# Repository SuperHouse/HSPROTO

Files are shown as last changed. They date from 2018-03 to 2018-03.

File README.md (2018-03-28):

HomeSense Proto
===============
Copyright 2018 SuperHouse Pty Ltd  www.superhouse.tv  
Designed by Jonathan Oxer

Prototyping module for ESP8266 projects in a small case suitable
for use in a home automation system. Includes:

 - ESP8266 processor with WiFi
 - Switchmode voltage regulator for wide input voltage range
 - Prototyping area with I/O breakout to add your own parts

More information at

  http://www.superhouse.tv/hsproto

INSTALLATION
------------
The design is saved as an EAGLE project. EAGLE PCB design software is
available from www.cadsoftusa.com free for non-commercial use. To use
this project download it and place the directory containing these files
into the "eagle" directory on your computer. Then open EAGLE and
navigate to the project.

DISTRIBUTION
------------
The specific terms of distribution of this project are governed by the
license referenced below.

LICENSE
-------
Licensed under the TAPR Open Hardware License (www.tapr.org/OHL).
The "license" folder within this repository also contains a copy of
this license in plain text format.

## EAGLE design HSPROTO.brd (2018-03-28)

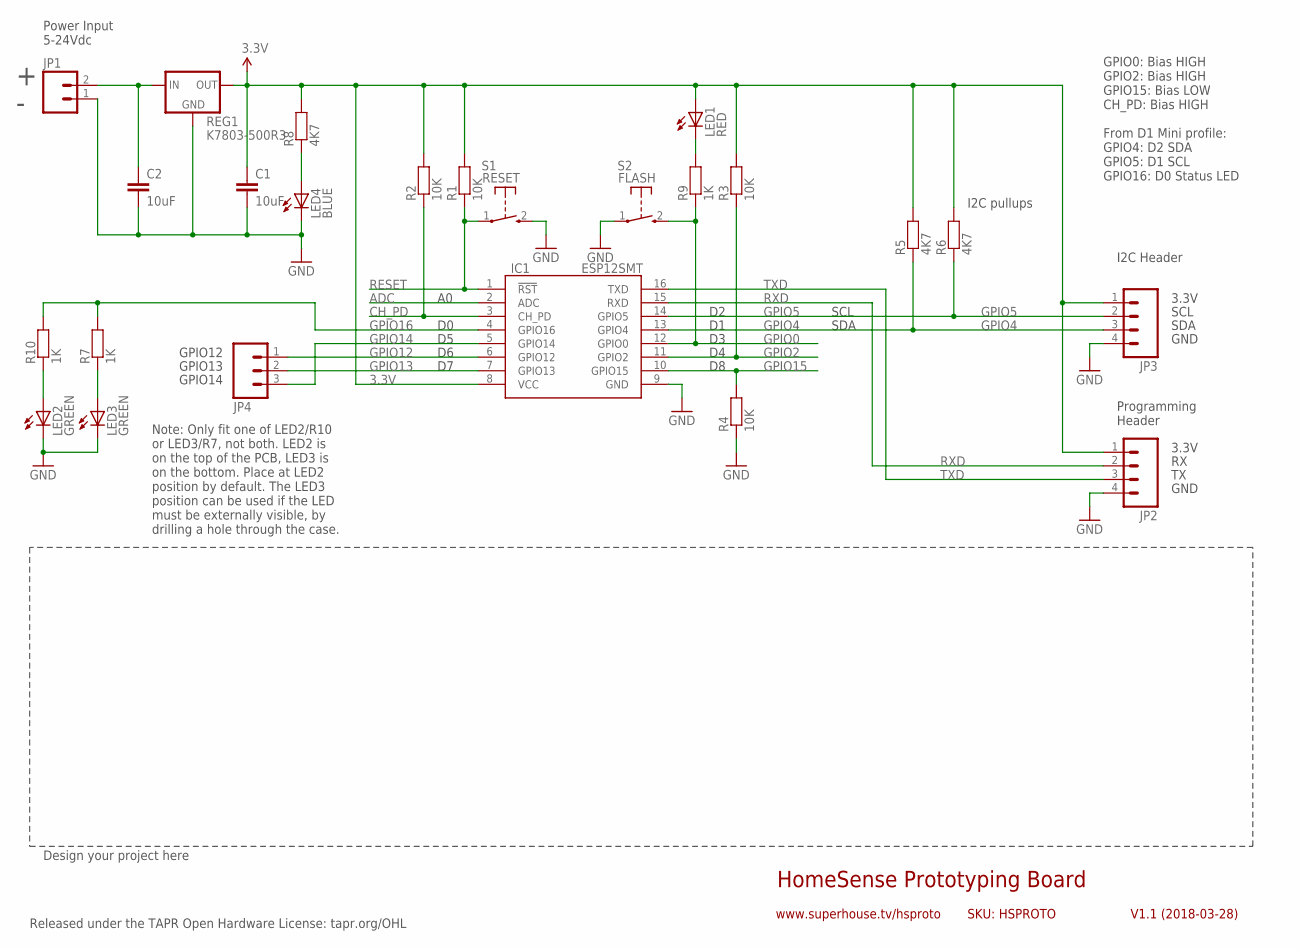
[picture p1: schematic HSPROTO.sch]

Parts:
C1, C2: 10uF; 0805
IC1: ESP12SMT; ESP12
JP1: M02PTH; 1X02
JP2, JP3: M04PTH; 1X04
JP4: M03PTH; 1X03
LED1: RED; LED-0603
LED2, LED3: GREEN; LED-0603
LED4: BLUE; LED-0603
R1, R2, R3, R4: 10K; 0603
R5, R6, R8: 4K7; 0603
R7, R9, R10: 1K; 0603
REG1: K7803-500R3; K78XX-500R3
S1: RESET; TACTILE_SWITCH_SMD_2PIN_TINY
S2: FLASH; TACTILE_SWITCH_SMD_2PIN_TINY

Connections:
3.3V: C1.1, IC1.8 (VCC), JP2.1, JP3.1, LED1.A, R1.2, R2.2, R3.2, R5.2, R6.2, R8.2, REG1.3 (OUT)
ADC: IC1.2 (ADC)
CH_PD: IC1.3 (CH_PD), R2.1
GND: C1.2, C2.2, IC1.9 (GND), JP1.1, JP2.4, JP3.4, LED2.C, LED3.C, LED4.C, R4.1, REG1.2 (GND), S1.2 (S), S2.1
GPIO0: IC1.12 (GPIO0), R9.1, S2.2 (S)
GPIO2: IC1.11 (GPIO2), R3.1
GPIO4: IC1.13 (GPIO4), JP3.3, R5.1
GPIO5: IC1.14 (GPIO5), JP3.2, R6.1
GPIO12: IC1.6 (GPIO12), JP4.1
GPIO13: IC1.7 (GPIO13), JP4.2
GPIO14: IC1.5 (GPIO14), JP4.3
GPIO15: IC1.10 (GPIO15), R4.2
GPIO16: IC1.4 (GPIO16), R7.2, R10.2
unnamed: C2.1, JP1.2, REG1.1 (IN)
unnamed: LED1.C, R9.2
unnamed: LED3.A, R7.1
unnamed: LED2.A, R10.1
unnamed: LED4.A, R8.1
RESET: IC1.1 (!RST), R1.1, S1.1
RXD: IC1.15 (RXD), JP2.2
TXD: IC1.16 (TXD), JP2.3

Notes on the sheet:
HomeSense Prototyping Board
V1.1 (2018-03-28)
www.superhouse.tv/hsproto
Released under the TAPR Open Hardware License: tapr.org/OHL
Design your project here
GPIO0: Bias HIGH GPIO2: Bias HIGH GPIO15: Bias LOW CH_PD: Bias HIGH From D1 Mini profile: GPIO4: D2 SDA GPIO5: D1 SCL GPIO16: D0 Status LED
3.3V
GND
Power Input 5-24Vdc
SDA
SCL
Programming Header
I2C Header
Note: Only fit one of LED2/R10 or LED3/R7, not both. LED2 is on the top of the PCB, LED3 is on the bottom. Place at LED2 position by default. The LED3 position can be used if the LED must be externally visible, by drilling a hole through the case.
I2C pullups
SKU: HSPROTO
GPIO14
GPIO12
GPIO13

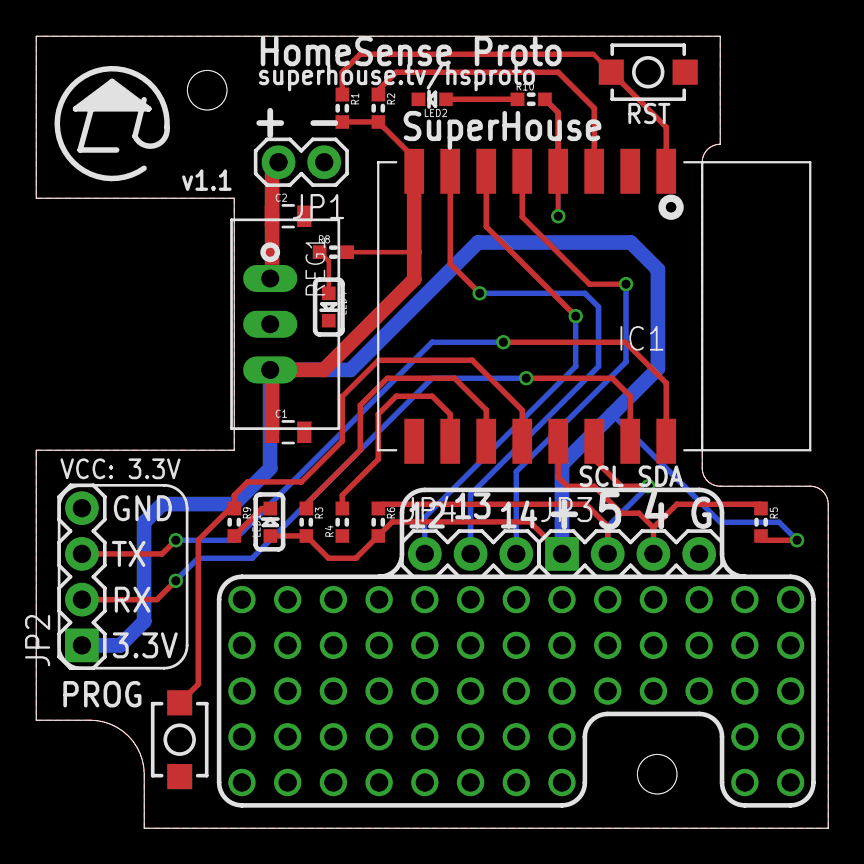
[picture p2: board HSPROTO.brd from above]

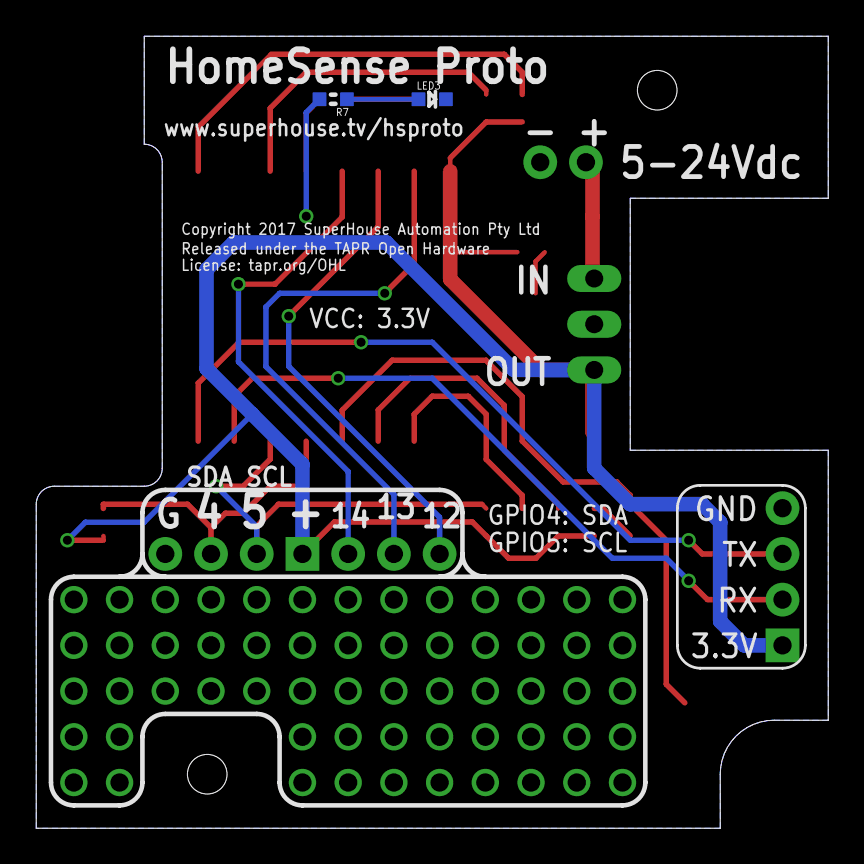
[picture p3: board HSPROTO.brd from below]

Board: 2 copper layers, 44.0 x 44.0 mm, 24 parts (2 on the bottom side), 20 nets.

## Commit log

2018-02-14 Initial project import
    [HomeSenseProto.brd, HomeSenseProto.sch]
2018-02-14 Added I2C header for proto area
    [HomeSenseProto.brd, HomeSenseProto.sch]
2018-02-16 Routing tweaks
    [HomeSenseProto.brd, HomeSenseProto.sch]
2018-03-04 Added more IO pins to breakout area
    [HomeSenseProto.brd, HomeSenseProto.sch]
2018-03-08 Updated routing and schematic for v1.0 release
    [HomeSenseProto.brd, HomeSenseProto.sch]
2018-03-28 Fixed footprint for ESP12 with correct GPIO4/5
    [HomeSenseProto.brd, HomeSenseProto.sch]
2018-03-28 Renamed project files
    [HSPROTO.brd, HSPROTO.sch]

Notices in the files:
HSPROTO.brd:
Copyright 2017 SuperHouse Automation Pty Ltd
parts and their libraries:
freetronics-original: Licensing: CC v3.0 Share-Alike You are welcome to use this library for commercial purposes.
